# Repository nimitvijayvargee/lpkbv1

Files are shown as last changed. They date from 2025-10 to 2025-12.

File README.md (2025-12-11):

# lpkbv1


This is my attpemt of making a wireless low profile keyboard. It uses the RP2040 in the form of a Pi Pico, and follows the ANSI75 layout. It is plateless mount, and can use a regular lipo or li-ion cell for wireless. It is designed with the Pico W in mind. The switches are following the Gateron KS-33 Low Profile switches, and any Low Profile MX keycaps (Cross Stem) can be used. The firmware is currently only QMK, but it does not support the wireless features of the keyboard. As of writing this, a KMK port which supports wireless is in the works.
 <br /> 
 <br/ >








## BOM
|Item |Price|Link |
|---|-----|---|
|PCB |100  |pcbpower.com |
|Keycaps |25 |[curiositycaps.in](https://curiositycaps.in/products/electrical-wire-slope-low-profile-side-printed-keycap)|
|Key switches |20 |[meckeys.com](https://meckeys.com/shop/accessories/keyboard-accessories/key-switches/gateron-low-profile-2-0-mechanical-switch-3pin/) |
|Diodes |2 |[robu.in](https://robu.in/product/1n4148-1w-zener-diode-pack-of-50/) |
|Schotkey Diode |0 |[robu.in](https://robu.in/product/1n5819-1w-diode-pack-of-30/) |
|Lipo Battery |5 |[quartzcomponents.com](https://quartzcomponents.com/products/3-7v-4000mah-li-po-rechargeable-battery) |
|Pico compatible ESP32-S3 Board |10  |[electronicscomp.com](https://www.electronicscomp.com/waveshare-esp32-s3-microcontroller-2.4-ghz-wi-fi-development-board-dual-core-processor-with-frequency-up-to-240-mhz)  | 
|Total |163  | |

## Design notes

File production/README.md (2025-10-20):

# Production files
1. gerber.zip - PCB Manufacturing Gerbers (Drill files included)
2. lpkbv1 case.3mf - Preconfigured slicer project (Orca slicer, Anycubic Kobra 2 Neo)
3. lpkbv1_default.uf2 - Default firmware file for the keyboard (QMK)
4. CPL.pos - Placement files (.pos)
5. CPL.csv - Placement files (.csv)
6. BOM.csv - PCB Assembly BOM (Only SMD Components)

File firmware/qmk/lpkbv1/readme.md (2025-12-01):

# lpkbv1

Use any Raspberry Pi Pico compatible board. QMK-Vial Firmware does not support wireless mode using the co-processor on the Pico W.
Wireless mode is planned as a future implementation based on micropython.

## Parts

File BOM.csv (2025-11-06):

Item | Price | Link
PCB | 100 | pcbpower.com
Keycaps | 25 | https://curiositycaps.in/products/electrical-wire-slope-low-profile-side-printed-keycap
Key switches | 20 | https://meckeys.com/shop/accessories/keyboard-accessories/key-switches/gateron-low-profile-2-0-mechanical-switch-3pin
Diodes | 2 | https://robu.in/product/1n4148-1w-zener-diode-pack-of-50
Schotkey Diode | 0 | https://robu.in/product/1n5819-1w-diode-pack-of-30
Lipo Battery | 5 | https://quartzcomponents.com/products/3-7v-4000mah-li-po-rechargeable-battery
Total | 153

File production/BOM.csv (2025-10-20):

Reference | Qty | Value | DNP | Exclude from BOM | Exclude from Board | Footprint | Part Number
C1,C2 | 2 | 4.7U |  |  |  | Capacitor_SMD:C_0402_1005Metric | Robu.in SKU R144036
C3 | 1 | 10u |  |  |  | Capacitor_SMD:C_0402_1005Metric | GPC0402106-6.3
R3,R9 | 2 | 10k |  |  |  | Resistor_SMD:R_0402_1005Metric | GPR040210K
R4,R5,R6 | 3 | 470 |  |  |  | Resistor_SMD:R_0402_1005Metric | GPR0402470R
R7 | 1 | 330K |  |  |  | Resistor_SMD:R_0402_1005Metric | Robu.in SKU R212713
R8 | 1 | 110K |  |  |  | Resistor_SMD:R_0402_1005Metric | Robu.in SKU R247554
R10 | 1 | 1k |  |  |  | Resistor_SMD:R_0402_1005Metric | GPR04021K
U1 | 1 | MCP73871 |  |  |  | Package_DFN_QFN:QFN-20-1EP_4x4mm_P0.5mm_EP2.5x2.5mm | Robu.in SKU R193409

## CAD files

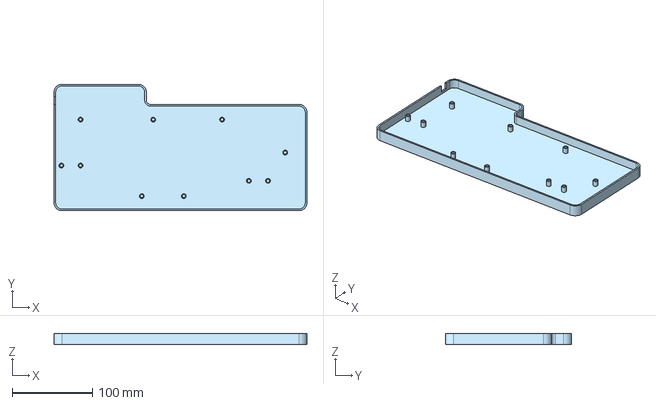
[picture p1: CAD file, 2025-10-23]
CAD/lpkbv1.step
315.0 x 157.5 x 14.0 mm

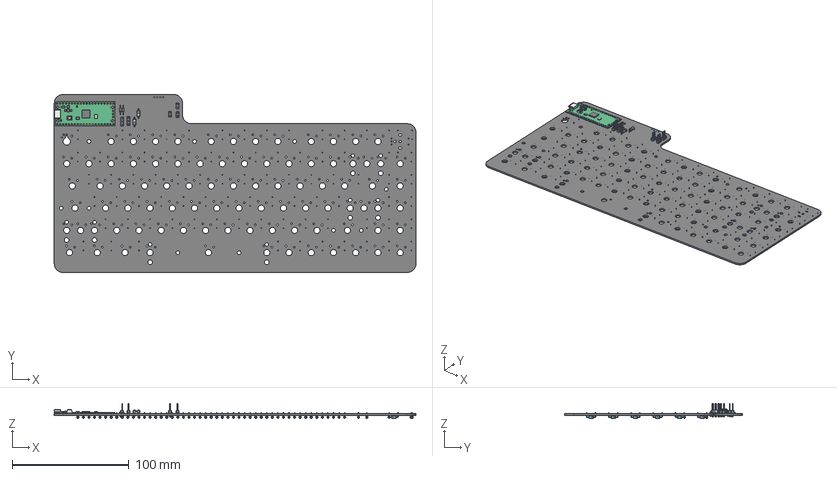
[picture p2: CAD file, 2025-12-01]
PCB/lpkbv1/lpkbv1.step
310.2 x 152.5 x 12.7 mm
PinHeader_1x03_P2.54mm_Vertical x 2
D_DO-41_SOD81_P7.62mm_Horizontal x 2
PinHeader_1x02_P2.54mm_Vertical x 3
R_Axial_DIN0204_L3.6mm_D1.6mm_P7.62mm_Horizontal x 2
RaspberryPi_Pico_Module_KiCad
D_DO-35_SOD27_P7.62mm_Horizontal x 82
lpkbv1_PCB

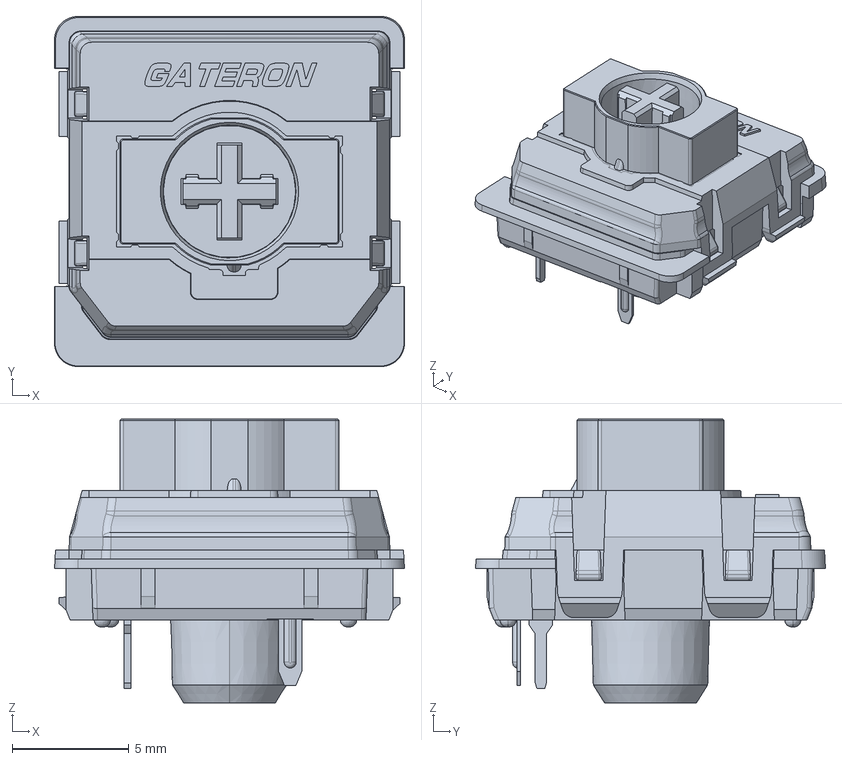
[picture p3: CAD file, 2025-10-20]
PCB/models/switch.step
15.0 x 15.0 x 12.1 mm

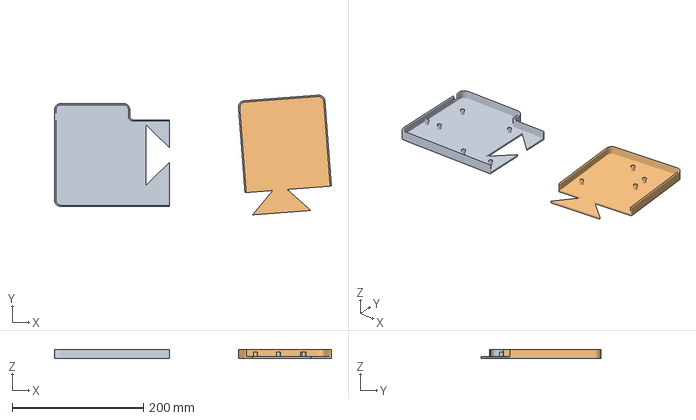
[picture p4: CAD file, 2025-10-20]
production/lpkbv1 case.3mf
422.5 x 182.7 x 14.0 mm
lpkbv1 case.stl_B
lpkbv1 case.stl_A

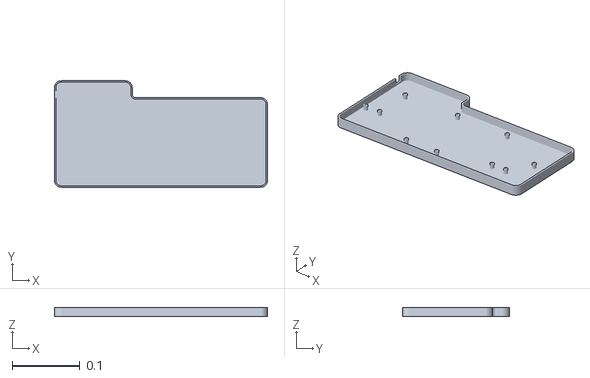
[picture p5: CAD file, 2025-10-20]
CAD/lpkbv1 case.stl
0.315 x 0.158 x 0.014

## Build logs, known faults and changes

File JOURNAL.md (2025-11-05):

<!--
  ===================    !!READ THIS NOTICE!!   ====================
  DO NOT edit this file manually. Your changes WILL BE OVERWRITTEN!
  This journal is auto generated and updated by Hack Club Blueprint.
  To edit this file, please edit your journal entries on Blueprint.
  ==================================================================
-->

## 10/1/2025 2 PM - Researched power system and battery requirements!  

Calculated some of the power stuff, which BMS board I can use and a couple of the things to calculate the overall charging system :). Connecting the Pico will be through a USB Micro B port. The VBUS will connect to the BMS for charging, and BMS to VSYS. This is the Breakout I plan on using, but probably won't expose the USB Port on it!
Screenshot From 2025-10-01 14-45-17.png

## 10/1/2025 3 PM - Make KLE Layouts!  

I made some KLE Layouts for Matrix and Label! Matrix is going to be required for Vial later on so I decided to do that right now. I also made the PCB Files and added them to the repo! Gonna start work on the schematic now :D. Also, why are low profile keycaps so expensive, and I don't even have aliexpress 😭😭



## 10/1/2025 4 PM - Completed the Schematic!  

Made a matrix and copy-pasted it to get the keyboard area. Then I used the research I did for the battery to make that area. The Pico and the encoder are standard, and the switches are MX. The 18650 also goes through a Voltage Divider to act as a Battery percentage somewhat. Finally, I set all the footprints for each symbol (thank you joe scotto) <br />
Screenshot From 2025-10-01 16-34-01.png

## 10/2/2025 - Laid out the PCB  

pretty fun, just set the grid sizes to the MX standard and went at it. Still debating where to put the 18650 holder, but i'll probably put it near the bottom or the top side of the keyboard
The stabs are hard to find for low profile keyborads, so i came up with a cursed alternative. Just put the stabs and two extra switches smh <br />
Screenshot From 2025-10-02 14-53-22.png

## 10/3/2025 - Added the diodes and routed some of the PCB  

Added the diodes and routed most of the rows and columns! Decided where to put the Pico (only used for charging) and now it looks very clean. The battery will be near the top so i'll have to expand the case (chamfer?) around that area; or just get a lipo instead. Overall, i am very close to completing the PCB <br />


## 10/6/2025 - power stuff  

tried to replace the shitty chinese charging thing with an actually good IC (the MCP73871). i have no idea how this works. my chatgpt free ended for today. i found a reddit thread from 2018 with no good answers. i need help. oh also the pcb looks pretty clean, i might replace the 18650 with a thin pillow, so i can expand the size later too!
  

## 10/9/2025 - Routed the rest of the PCB  

Got the new power stuff working and routed the rest of the PCB. Also managed to figure out the PSU, although I might need to fix the resistors around. I also added an OLED screen. There is a cool thing where i exported the PCB as dxf and imported it onto the silkscreen, just because; and it honestly looks pretty cool ngl. The edge cuts is temporary, just so the board renders properly. Might round it off later or clean up the areas.


## 10/10/2025 4 PM - Finished the PCB  

I finally finished the PCB! Now everything looks (and hopefully works) awesome! Still debating between a black on white or white on black design, but it will definitely have acrylic on the case :yesyes:. Anyways check out the picture of the design! Rounded corners will be translated into the cad (2.5mm, 1cm is too much, i learn).


## 10/10/2025 6 PM - CAD!!!  

Learning freecad definitely has a curve to it, but it runs awesome unlike fusion. I am too used to fusion so it took me more than an hour to fix up the outline sketch of the case. After that, I need to add the mounting holes (also to the PCB, i forgot those) and  the slot for the acrylic cover!


## 10/11/2025 - Rerouted the PCB again  

Turns out gateron KS-33 LP have different footprints, so there goes my saturday. I also reinstalled kicad so i could get the 3d models rendering properly, and my god is it pretty. Tried the 18650, didn't like and am sticking with a 4000mAh lipo battery
here is the nice PCB now





## 10/13/2025 - CAD (2)  

Freecad wasn't right for me, so I went to onshape to learn. I started with the basic keyboard, added the screws and set up the walls. Thin (2.5mm) walls and a not that large area of coverage. I will also need to figure out the way to slide in the battery but that's a future me problem. I'll probably sandwich the battery and then screw in a top case, screw the PCB into that.


## 10/20/2025 - Finshed the CAD  

Keyboard CAD! I should be able to fit the battery in there, everything else looks perfect. idk why the inserts are different colours but eh. also it was kinda fun to make all this now that i look back. time to make the bom and submit this :yay:. here is some padding text to reach the word count :thumbup:


## 11/5/2025 - Redid the power   

Changed it up to use a good ol' TP4056 IC i have lying around, and make it function just as good with 2 schotkey diodes! the pcb is a pain, but I didn't change much so mountin should be the same


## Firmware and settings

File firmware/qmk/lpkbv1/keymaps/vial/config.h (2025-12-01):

#pragma once

#define VIAL_KEYBOARD_UID {0xAB, 0xBC, 0xCD, 0xDE, 0xEF, 0xCF, 0x07, 0x13}

#define VIAL_UNLOCK_COMBO_ROWS { 0, 0 }
#define VIAL_UNLOCK_COMBO_COLS { 0, 2 }

#define OLED_DISPLAY_128X64
#define OLED_IC SSD1306

#define I2C1_SDA_PIN GP26
#define I2C1_SCL_PIN GP27
#define I2C_DRIVER I2CD1

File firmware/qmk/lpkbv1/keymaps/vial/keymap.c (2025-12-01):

// Copyright 2023 QMK
// SPDX-License-Identifier: GPL-2.0-or-later

#include QMK_KEYBOARD_H

const uint16_t PROGMEM keymaps[][MATRIX_ROWS][MATRIX_COLS] = {

    [0] = LAYOUT_75_ansi(
        KC_ESC, KC_F1, KC_F2, KC_F3, KC_F4, KC_F5, KC_F6, KC_F7, KC_F8, KC_F9, KC_F10, KC_F11, KC_F12, KC_MPLY,
        KC_GRV, KC_1, KC_2, KC_3, KC_4, KC_5, KC_6, KC_7, KC_8, KC_9, KC_0, KC_MINS, KC_EQL, KC_BSPC, KC_DEL,
        KC_TAB, KC_Q, KC_W, KC_E, KC_R, KC_T, KC_Y, KC_U, KC_I, KC_O, KC_P, KC_LBRC, KC_RBRC, KC_BSLS, KC_PGUP,
        KC_CAPS, KC_A, KC_S, KC_D, KC_F, KC_G, KC_H, KC_J, KC_K, KC_L, KC_SCLN, KC_QUOT, KC_ENT, KC_PGDN,
        KC_LSFT, KC_Z, KC_X, KC_C, KC_V, KC_B, KC_N, KC_M, KC_COMM, KC_DOT, KC_SLSH, KC_RSFT, KC_END,
        KC_LCTL, KC_LGUI, KC_LALT, KC_SPC, KC_RALT, KC_NO, KC_RCTL, KC_LEFT, KC_DOWN, KC_RIGHT, KC_UP
    )

};

#if defined(ENCODER_MAP_ENABLE)
const uint16_t PROGMEM encoder_map[][NUM_ENCODERS][NUM_DIRECTIONS] = {
    [0] = { ENCODER_CCW_CW(KC_MPRV, KC_MNXT)  },
};  
#endif

bool oled_task_user(void) {
    oled_write_ln_P(PSTR("lpkbv1 QMK-VIAL"), false);
    oled_write_ln_P(PSTR(""), false);
    oled_write_ln_P(PSTR("Wired Mode"), false);
    oled_write_ln_P(PSTR(""), false);
    led_t led_state = host_keyboard_led_state();
    oled_write_ln_P(led_state.caps_lock ? PSTR("CAP ") : PSTR("    "), false);
    
    os_variant_t os = detected_host_os();

switch (os) {
    default:
        oled_write_ln_P(PSTR("Host OS: Unknown"), false);
        break;
    case OS_UNSURE:
        oled_write_ln_P(PSTR("Host OS: Unknown"), false);
        break;
    case OS_WINDOWS:
        oled_write_ln_P(PSTR("Host OS: Windows"), false);
        break;
    case OS_MACOS:
        oled_write_ln_P(PSTR("Host OS: MacOS"), false);
        break;
    case OS_LINUX:
        oled_write_ln_P(PSTR("Host OS: Linux"), false);
        break;
    case OS_IOS:
        oled_write_ln_P(PSTR("Host OS: iOS"), false);
        break;
}

    return false;
}

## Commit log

2025-10-01 Add PCB Files
    [lpkbv1.kicad_pcb, lpkbv1.kicad_sch]
2025-10-23 Ship ready!
    [lpkbv1.kicad_sch, lpkbv1.step]
2025-12-01 Firmware fix + gerber fix
    [lpkbv1.kicad_sch, lpkbv1.step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]
